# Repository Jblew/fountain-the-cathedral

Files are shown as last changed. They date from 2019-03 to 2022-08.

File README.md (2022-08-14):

# Water Fountain "The Cathedral"

The story behind:

1. AD 1882 — [Antoni Gaudí](https://en.wikipedia.org/wiki/Antoni_Gaud%C3%AD) builds the [Sagrada Família church](https://en.wikipedia.org/wiki/Sagrada_Fam%C3%ADlia)

2. AD 2000 — The Sagrada Familia church inspires [Jacek Dukaj](https://pl.wikipedia.org/wiki/Jacek_Dukaj) to write a short story — ["The Cathedra"](https://pl.wikipedia.org/wiki/Katedra_(opowiadanie)).

3. AD 2002 — [Tomasz Bagiński](https://en.wikipedia.org/wiki/Tomasz_Bagi%C5%84ski) ilustrates the story with his wonderful (and at that time technically astonishing) [animation "The Cathedral"](https://en.wikipedia.org/wiki/The_Cathedral_(film)).

4. AD 2019 — After seeing the Church, watching the Animation and reading the Story (in this order) I decided to build a tribute to the Three Great Artists: Gaudi, Dukaj and Bagiński

They have already used three art techniques: architecture, literature and digital animation. To continue the chain of inspiration I had to choose a different one. 

... continue

## Update

### Stage 1

[See photos](./stage_1/photos.md)

**Done**:

1. Built cathedral backbone of copper wire
2. Secured the backbone with styro foam

### Stage 2

[See photos](./stage_2/photos.md)

**Done:**

1. Selected and prepared 2 granite stones
2. Drilled fi12mm holes for the supporting rods (3 holes in the smaller stone and 7 in the bigger one)
3. Drilled 19 fi8mm holes to attach the cathedral building

**Comment:**

I used diamond hole-saws together with constant water flow (using 450l/h pump). Despite using the maximum rotation speed of the driller it took more than 16 hours to drill all the holes. During the drilling I destroyed 4 saws.

### Stage 3

[See photos](./stage_3/photos.md)

**Done:**

1. I drilled the "magnum foramen" through the centre of the bigger stone. Because of the limited length of the hole-saws I had to mark the position stereotactically and then drill separate holes on each side. Then I used a hammer and steel rods to carefoully chisel the remaining stone from inside.
2. On the upper side I widened the foramen opening using diamond mills (spindle- and ball-shaped). Thanks to that I achived an "anxious" look of the dark and deep hole. What is more — thanks to the wide opening — woter that is flowing upwards through the tunnel doesn't "shoot" in a fountain-like manner. Instead it flows slowly.
3. I drilled many glens, gorgens and faults to guide the direction of water flow. After the procedures water is flowing only in the front direction spreading into an elegant and majestic delta.
4. I drilled supporting tunnels that connect with the main foramen and open on the front waterfall. The idea is to have limited amount of water flowing through the floor of the cathedral while maintaining high flow through the waterfall.

### Stage 4

[See photos](./stage_4/photos.md)

**Done:**

1. First, I encountered a problem of creating a plane model of holes of the bottom side of both stones. When I was drilling them they often were misplaced compared to the original stencil. I had to position the stones correctly and then somehow create another plain stencil. Positioning was demanding since the stones are very heavy. i used wooden blocks and old clothes to precisely position them. To create a stencil I put a huge transparent acrylic glass onto the stones. Using a laser (which I ensured that was staying in a perfectly right angle to the glass) I ensured that the laser dot appears exactly in the middle of each hole. Then I marked the laser spots on the glass. Next step was to drill the holes through the acrylic and copy the appertures of the holes to a semi-transparent engineering paper.
2. Using the stencils I drilled the same set of holes in a wooden 600x600mm shelf which then I hanged above the stones. I inserted fi12mm rods both into the wells in the stones and the holes in the hanging piece of wood. I had to position it using steel wires attached to the ceiling and walls. I used level tool a lot to ensure that all the angles are correctly positioned.
3. I marked the position of the wooden plane on the rods, labelled them with numbers (put the same numbers on the stencil) — and then I cut each rod to end at the exact position of the plane. 
4. After I had each rod lengthened properly  I secured them to the plane with nuts and steel rings which also prevented the plane from oscillating on the steel wires.
5. Then the most time consuming process begun. I had to attach the rods to the stone in an extremly strong and reliable manner. The best idea that appealed to me was to use a "chemical anchor". After studying chemical and physical specs of several of such products I bought a Pattex chemical anchor that was waterproof and was designed exactly for connecting steel and stone. A chemical anchor consists of two ingredients that mix up in a special mixer attached at the end of aplying tool and then are applied directly into the holes.
6. Over the next 4 weekends I was unscrewing 3 rods each time and apply the chemical anchor. Then I needed to leave it for about 18 hours to get a strong bond. Almost half of them didn't mount securely at the first appliance and I had to clean the holes, drill-out the artificial sand and apply it one more time.

### Stage 5

[See photos](./stage_5/photos.md)

**Done:**

1. Built temporary base mad of three old wooden 600x600 shelves
2. Assembled base and the stones on the rods in a vertical position
3. Connected the pump to the bottom tunnel to test the waterflow
4. Using diamond mills I deepened the glens to guide the waterflow in a more even way
5. Sharpened the bottom edge of the fall to prevent water underflowing (and thus corroding the steel rods) 

### Stage 6

[See photos](./stage_6/photos.md)

**Done:**

1. Cleaned the stones with pressure cleaner
2. Removed stone impurities with diamond and corund mills
3. Glued the cathedral backbone using poxillin glue

### Stage 7

[See photos](./stage_7/photos.md)

**Done:**

1. Removed the temorary base
2. Built a new base made of 4x 18mm plywood planes and applied a black glass ontop of that
3. Attached 8 aluminium u-profiles to separate the plywood from the floor.

### Stage 8

(no photos)

1. Designed a way to quickly attach nuts
2. Disassembled old base
3. Covered the entire monument with foil to protect it for the winter (it sits outside)
4. Ordered steel plates to stabilise the rods that support the heavy rocks. I designed an SVG then converted it to CAD file (with some minor adjustments). I ordered laser cutting of 6mm black steel (should get covered with rust very quickly!)
5. Ordered the flowerpot which will be the water reservoir. I have choosen a 300x600x390 one, made of fiberglass with very shiny finish. It's said to be very durable yet it weights only 4kg (compared to concrete ones which (at the same size) weight around 30kg)

### Stage 9

TODO photos

1. Designed and ordered laser-cut steel support plates for water reservoir. Still not assembled

### Stage 10

(no photos)

1. Designing and planning waterfall disperser
2. Main idea: ceramic maple leaves

### Stage 11

Plan:

1. Assemble reservoir circuit
   1. Plan hole positions
   2. Make holes
   3. Apply liquid rubber isolation
   4. Attach electric & water culverts to the reservoir
2. Build reservoir support
   1. Plan height & lengths of rods
   2. Cut feet rods
   3. Make feet holes in the base glass
   4. Make feet holes in the base plywood
   5. Screw on feet rods
3. Build electric 
4. Assemble major parts together
   1. Attach steel stabilisers to the long rods
   2. Attach base to the long rods
   3. Attach reservoir

## Setting

width: 75cm wall + 7cm door border

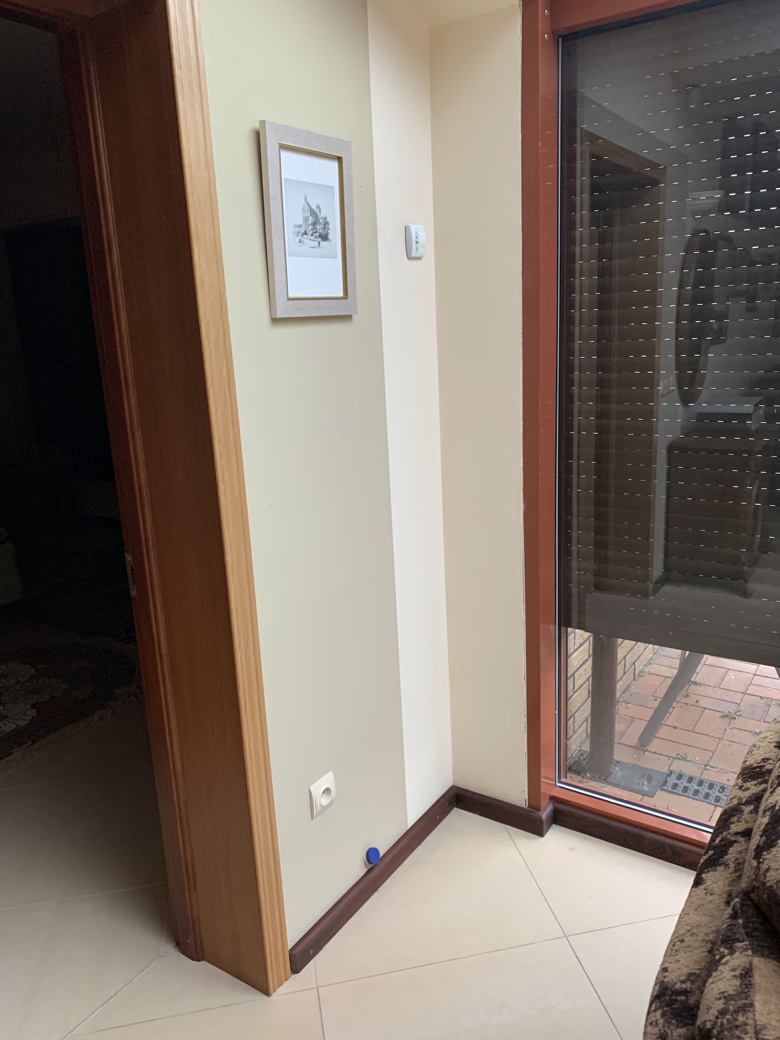
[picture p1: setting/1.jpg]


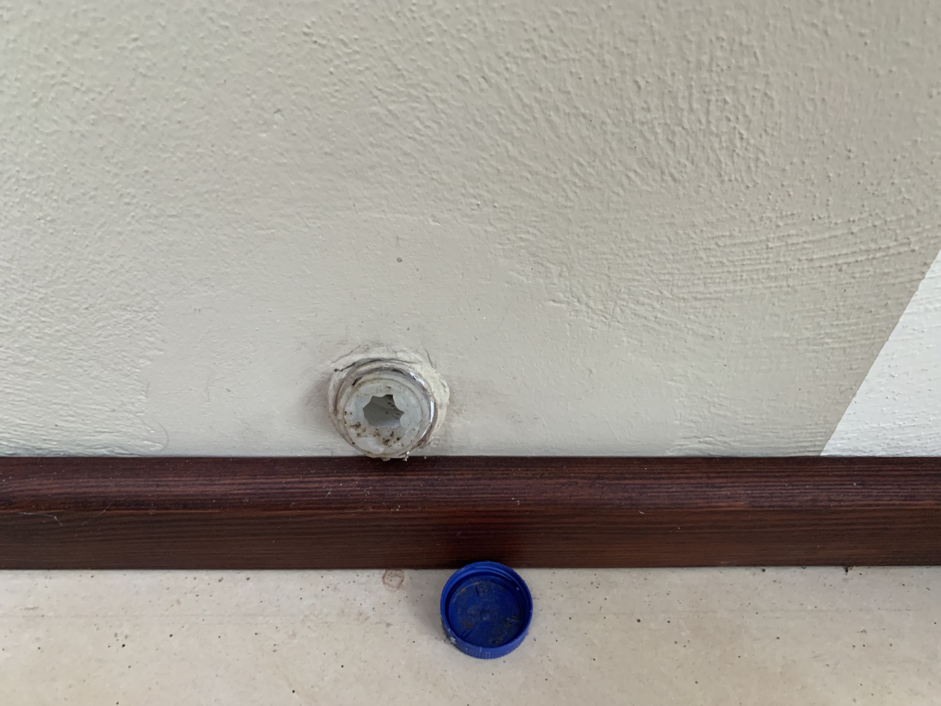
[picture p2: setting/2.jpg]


## Plans

### Steel rods stabilisers

Position of holes (relative to the base — left,deep):

1. 160,302 = 302-160 => 160,142
2. 253,373
3. 298,279
4. 275,157
5. 413,151
6. 494,177
7. 430,279
8. 78,249
9. 102,169
10. 169,157

Todo:

1. Order steel stabilisers

## Water reservoir

Candidates:

1. https://sklep.polnix.com.pl/pl/p/95.010/144
   1. czarna, włókno szklane
   2. 2,9kg, 70l, tj razem z wodą max 70/2+2,9=37,9kg
   3. w=600,d=300,h=390 [mm]
2. https://sklep.polnix.com.pl/pl/p/95.038/133 (jw, ale z nóżkami)

TODO:

1. Design support/fulcrum for the pot (should be anchored in the wooden base and do not burden the glass plane)

## Todo

**Structure:**

1. Stabillise rods that are supporting the stones with:
   1. (either) small welded horizontal rods
   2. (either) use multiple convolutions of thick nickel plated wire attached with nuts and glue shaped into ivory-like structure
   3. (either) use thick barbed wire attached with nuts and glue
2. Apply rusting mixture to rust the rods. (If using nickel wires to stabilise the supporting rods: scratch the nickel wires with coarse-grained emery paper). Then secure the rust with water resistant transparent (and nonglowing!) coat.

## Water circuit

Reservoir

Pump circuit:

1. - [x] Nypel 1/2" -> 3/4" m/m
2. - [x] Wąż 3/4" f/f 100cm (internal fi 19mm)
3. - [x] Nypel 3/4" m/m
4. - [x] Redukcja nypel 3/4" -> mufa 1"
5. - [x] Przepust m1" -> f3/4"
6. - [x] Nypel 3/4" m/m
7. - [x] Wąż 3/4" f/f 30cm (internal fi 19mm)
8. - [x] Nypel m3/4" -> f1/2"
9. - [x] Nypel 1/2" -> plastik 13mm (dołączony do pompy)

Reservoir refill circuit

1. - [x] 2x Przepust f1/2" -> m3/4"
2. - [x] 2x Wąż 3/4" f/f 50cm (internal fi 19mm)
3. - [x] 2x Nypel m3/4" -> f1/2"
4. - [x] 2x elektrozawór 1/2" m/m
5. - [x] 2x zawór kulowy 1/2" f/m
6. - [x] 2x wąż 1/2" 150cm m/m

**Cathedral:**

1. Coat the cathedral with copper wire of decreasing sizes
2. Design and build the Altar
3. Design 3D model of the Priest and order it
4. Design 3D model of Saint Ismir's grave
5. Form and attach a Cross on the top
6. Distort the shape of the fully assembled cathedral so that it looks haunted and almost falling
7. Apply blue-copper-corrosion mixture and secure with transparent (glowing!) coating

**Water system:**

1. Choose and buy flowerpot for a tank
2. Design and assembly water automation
3. shape the waterfall edge to ensure that water is flowing into the tank without spilling

**Plants:**

1. Buy and attach Hedera helix ivory (darkest possible shade of the leaves)
2. Design and assembly ivory watering system

**Target site assembly:**

1. Mount black glass to the wall behind the fountain to prevent destroying wall plaster, also if the background is black and glowing:  the base, rods, ivory, the stones will be less striking while emphasizing the blue-and-ginger glowing cathedral.

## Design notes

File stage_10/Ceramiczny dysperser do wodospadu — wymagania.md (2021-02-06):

# Ceramiczny dysperser do wodospadu — wymagania

1. Ceramika: czarna, szkliwiona na połysk
2. Liście w trzech rozmiarach, odpowiednio do naturalnych liści klonu. 14x duży liść, 14x średni liść, 14x mały liść
3. 2 otwory w każdym liściu, przy podstawie — średnica od 5mm do 8mm, odległość od 10 do 15mm pomiędzy nimi
4. Każdy liść lekko zagięty na brzegach i do wewnątrz (skulony), tak, żeby niewielka ilość wody mogła się tam zebrać (one będą zamontowane pod kątem 45 stopni do pionu)

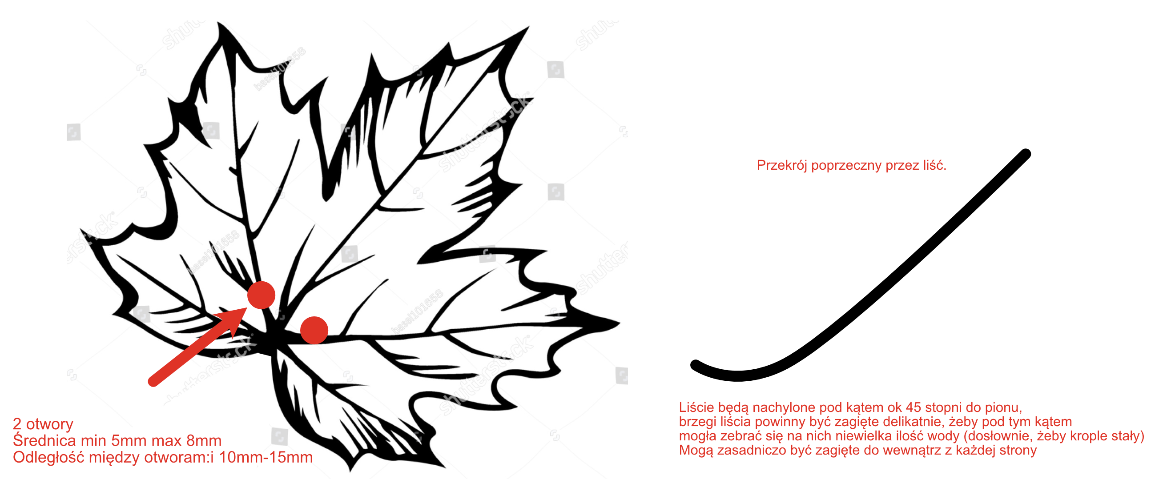
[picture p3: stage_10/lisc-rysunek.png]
lisc-rysunek


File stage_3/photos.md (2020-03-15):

# Stage 3 photos

[Back to the README](../README.md)











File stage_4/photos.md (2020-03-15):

# Stage 4 photos

[Back to the README](../README.md)

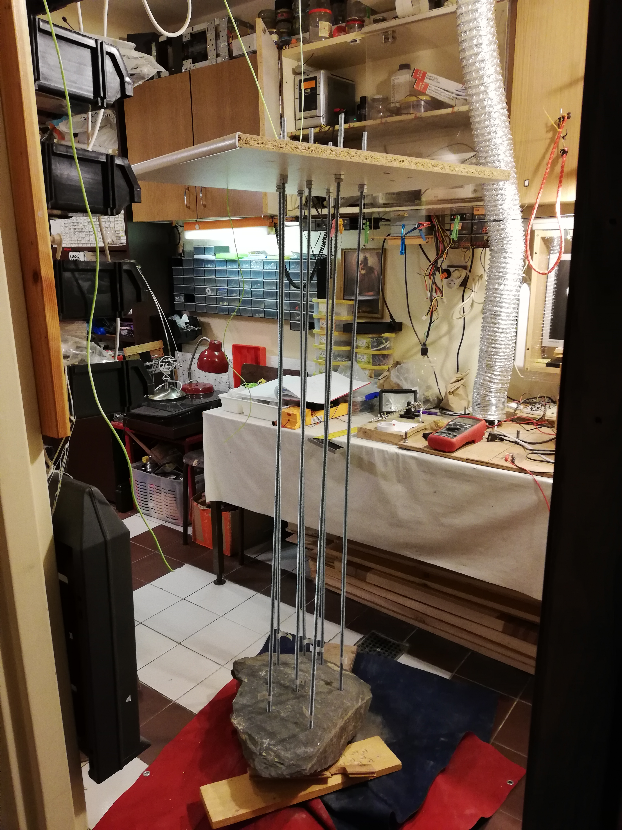
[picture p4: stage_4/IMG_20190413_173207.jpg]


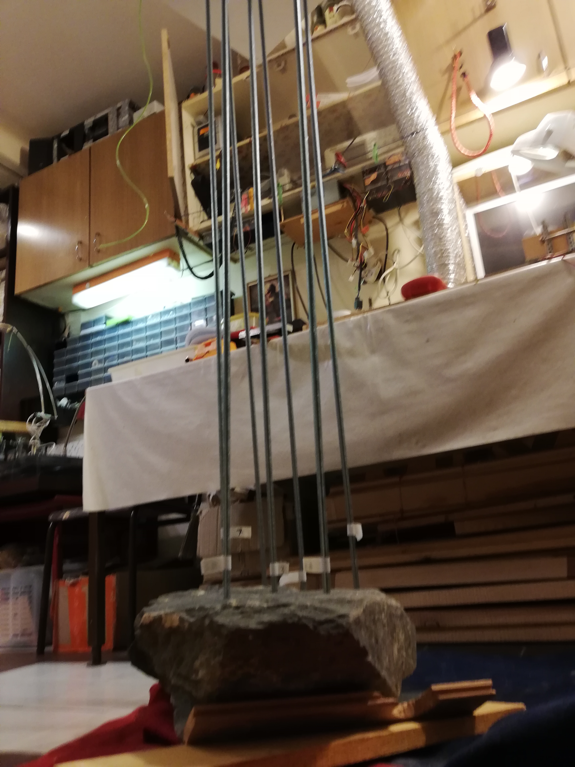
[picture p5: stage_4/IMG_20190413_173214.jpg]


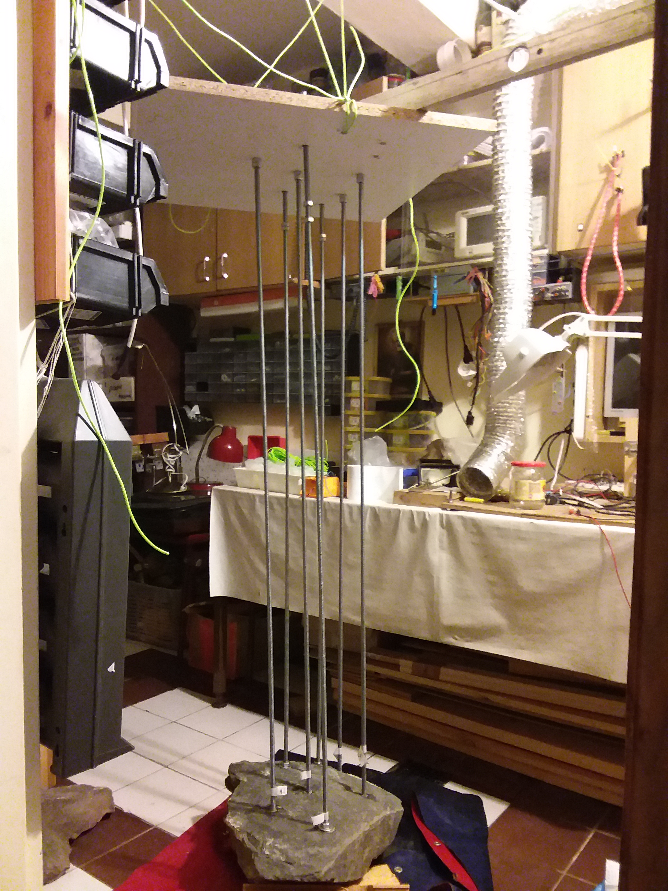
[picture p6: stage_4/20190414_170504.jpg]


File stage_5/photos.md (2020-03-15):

# Stage 5 photos

[Back to the README](../README.md)

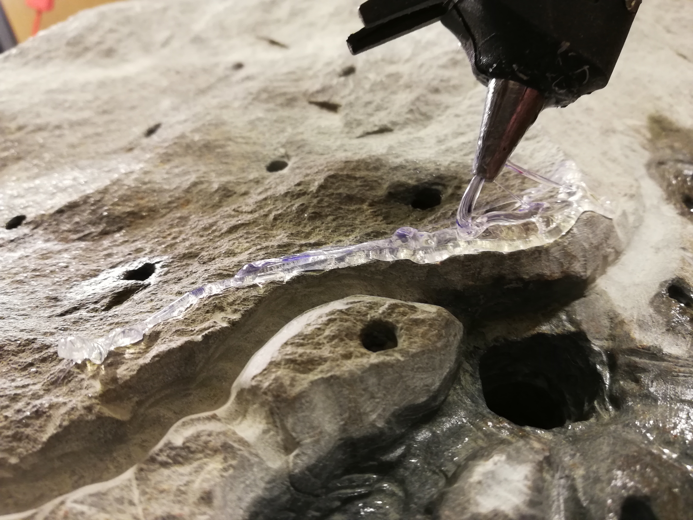
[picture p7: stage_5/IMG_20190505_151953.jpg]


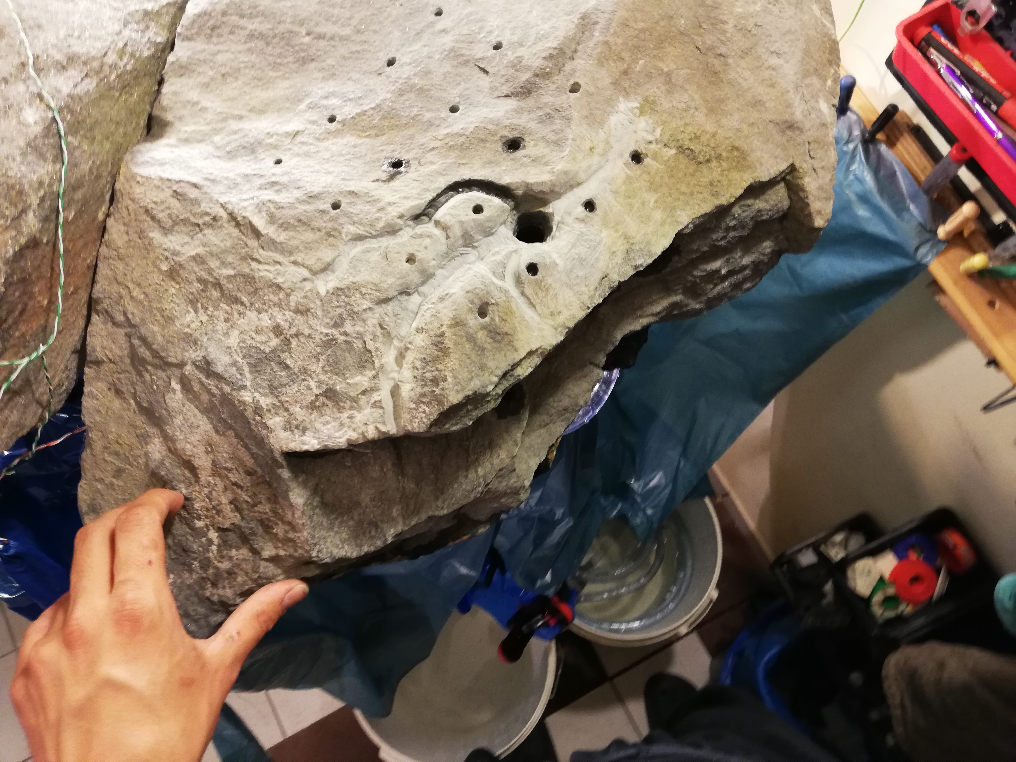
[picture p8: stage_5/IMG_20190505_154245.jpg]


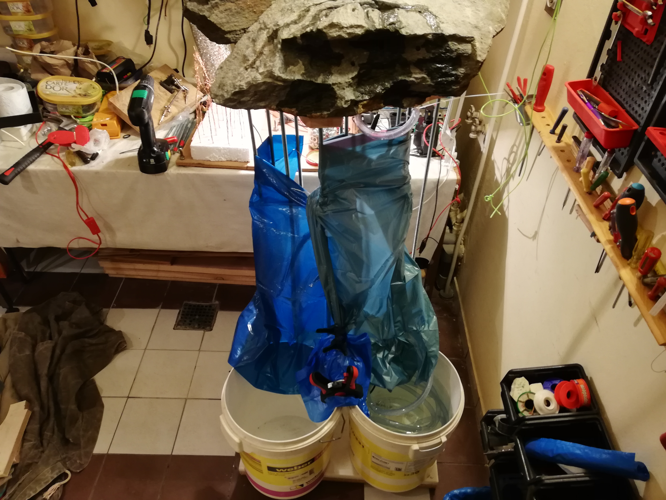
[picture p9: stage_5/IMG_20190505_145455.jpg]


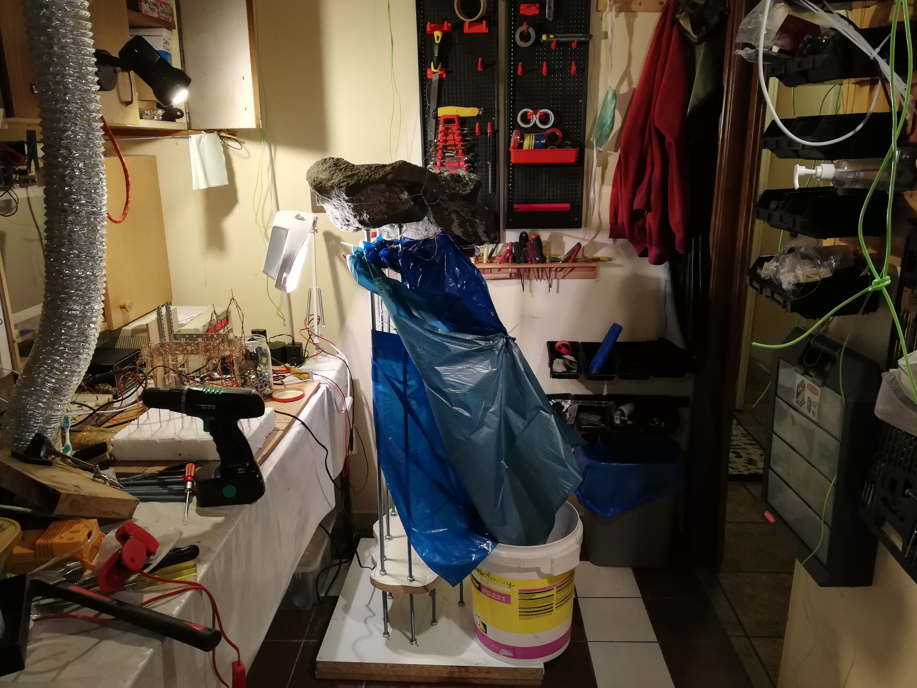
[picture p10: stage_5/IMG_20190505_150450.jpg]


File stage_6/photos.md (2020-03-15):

# Stage 6 photos

[Back to the README](../README.md)











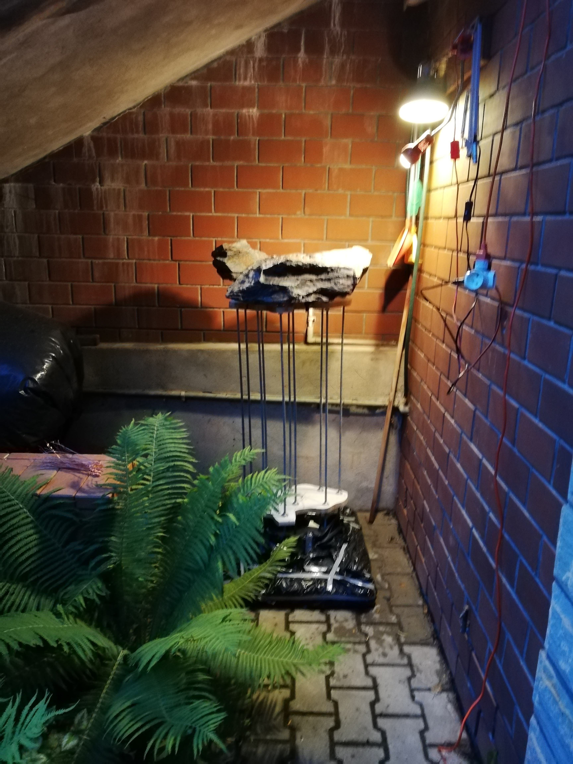
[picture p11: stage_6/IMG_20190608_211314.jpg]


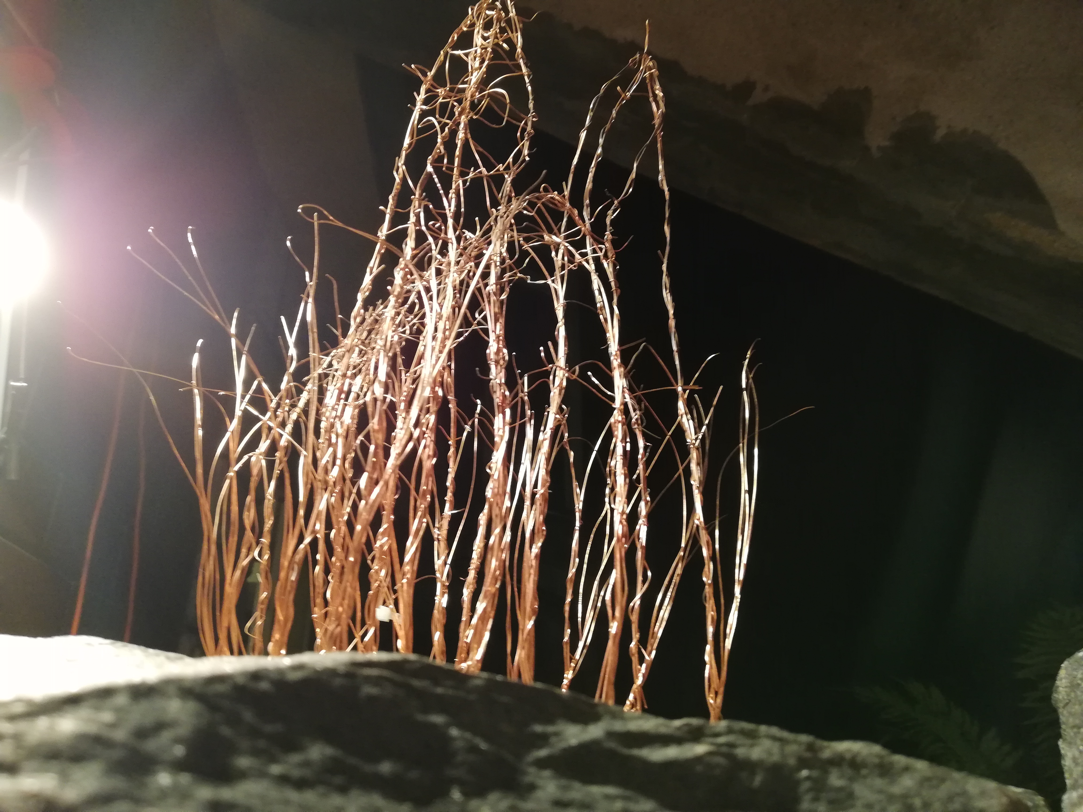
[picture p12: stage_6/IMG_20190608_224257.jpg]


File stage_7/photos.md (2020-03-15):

# Stage 7 photos

[Back to the README](../README.md)

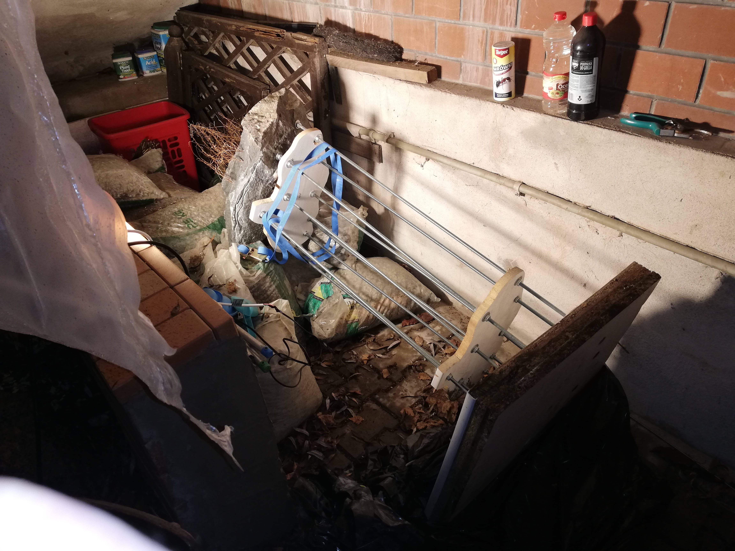
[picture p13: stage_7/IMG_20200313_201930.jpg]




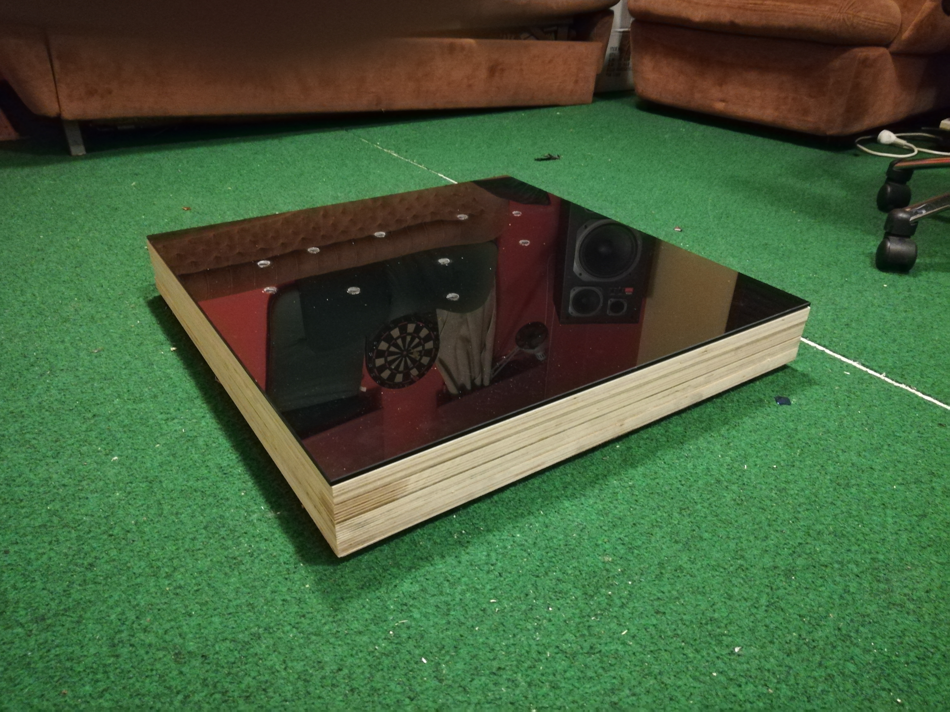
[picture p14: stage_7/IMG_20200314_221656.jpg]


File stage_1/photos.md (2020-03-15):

# Stage 1 photos

[Back to the README](../README.md)

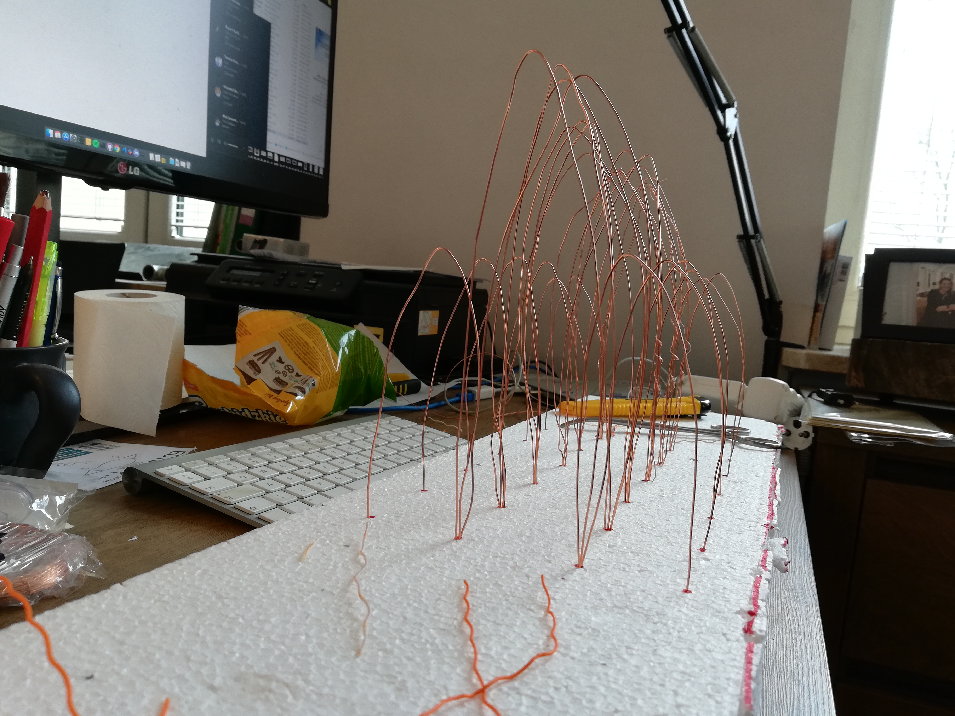
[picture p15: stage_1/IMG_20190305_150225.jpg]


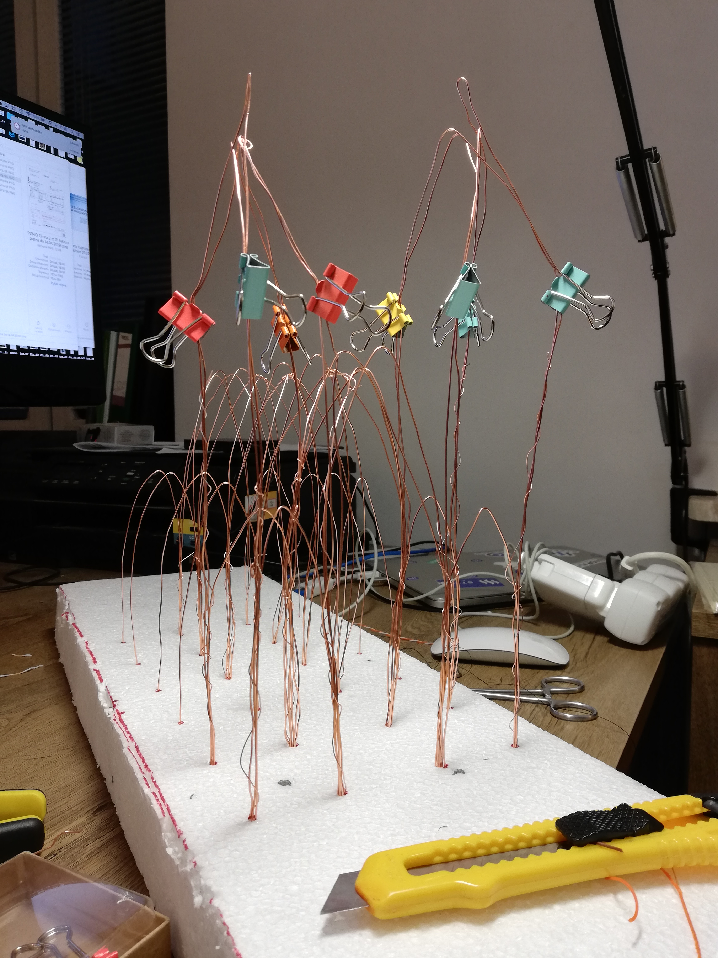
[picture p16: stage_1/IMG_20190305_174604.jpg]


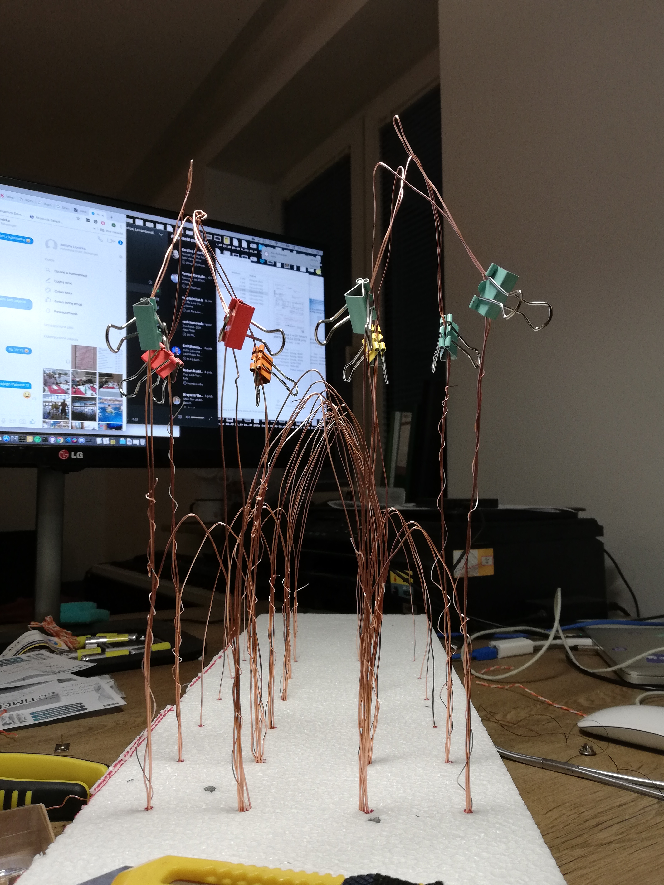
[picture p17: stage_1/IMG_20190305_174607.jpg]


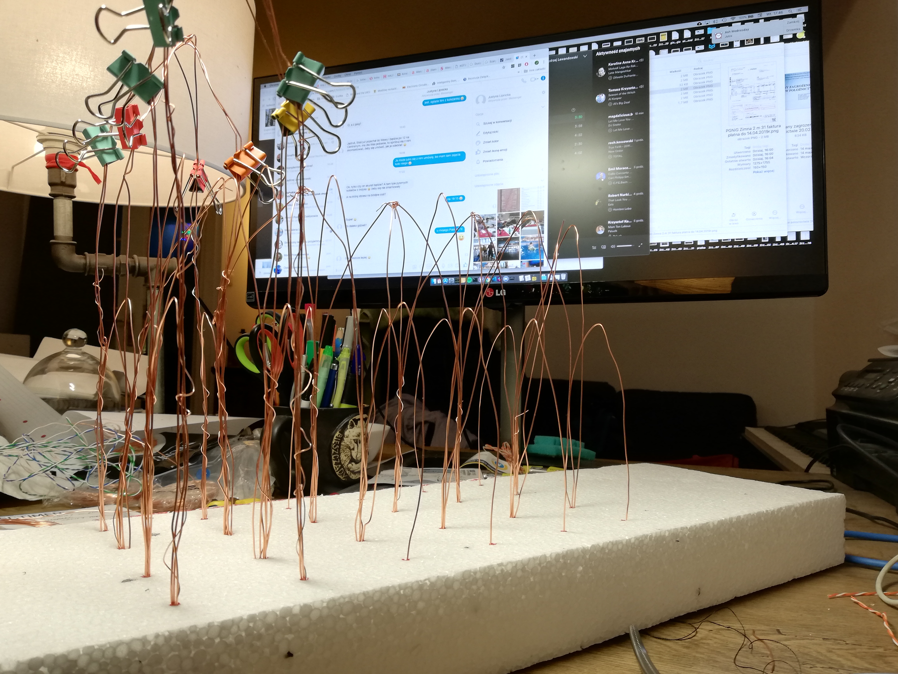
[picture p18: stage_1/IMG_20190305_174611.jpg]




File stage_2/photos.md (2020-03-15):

# Stage 2 photos

[Back to the README](../README.md)













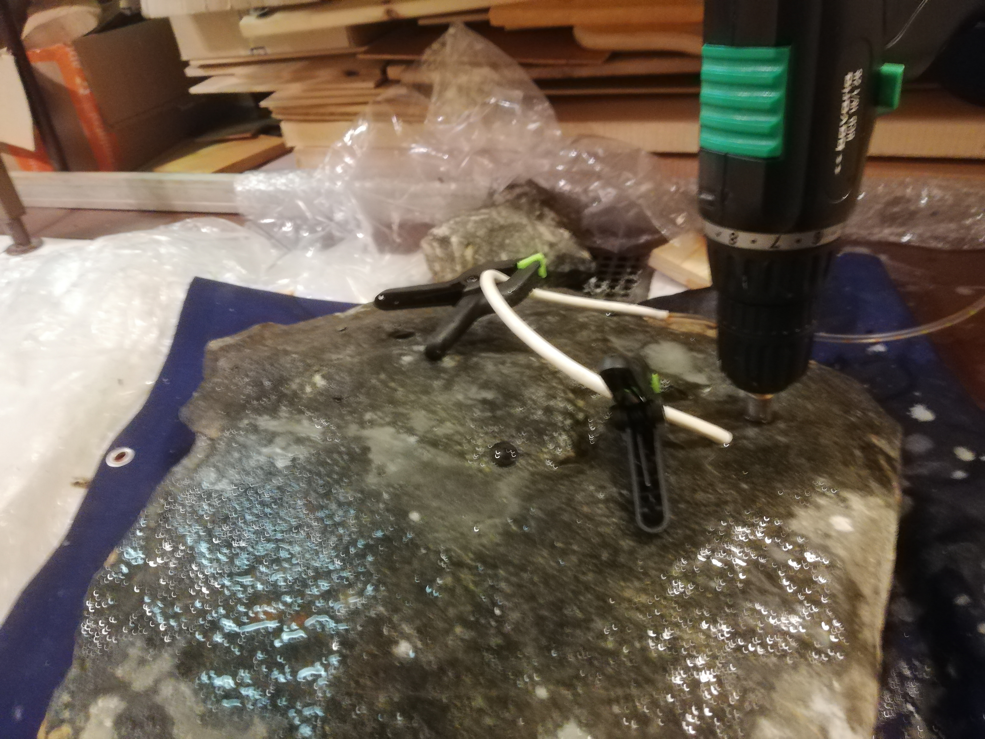
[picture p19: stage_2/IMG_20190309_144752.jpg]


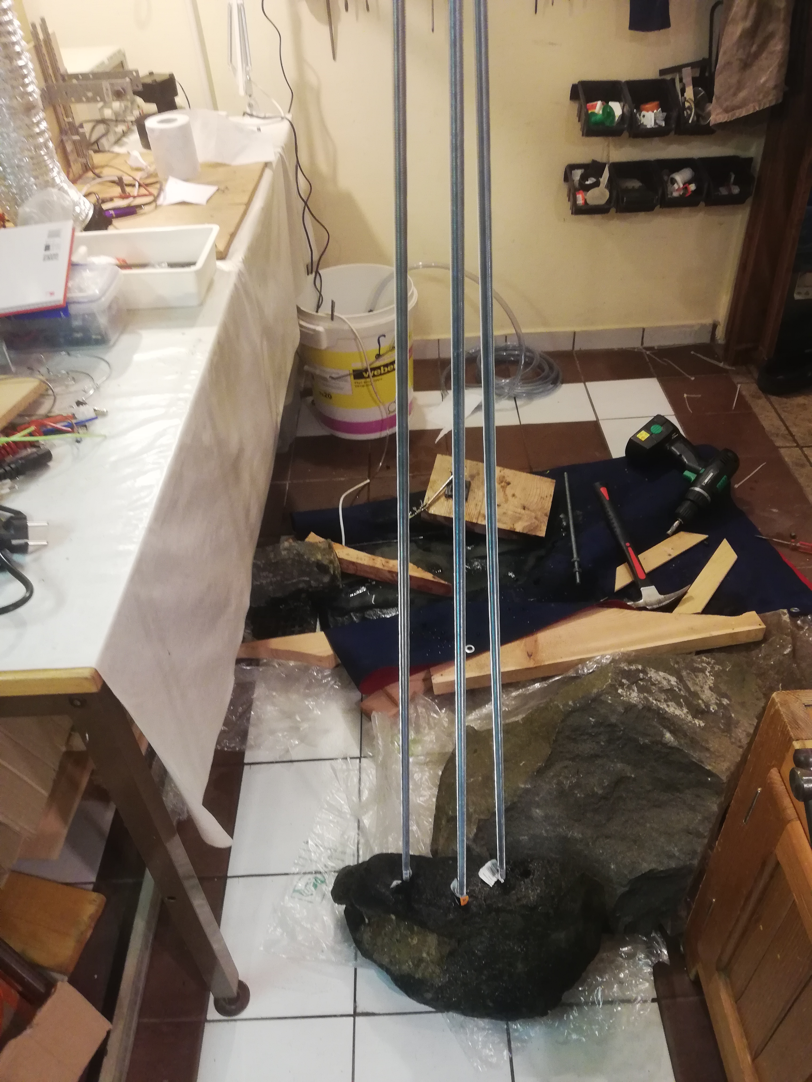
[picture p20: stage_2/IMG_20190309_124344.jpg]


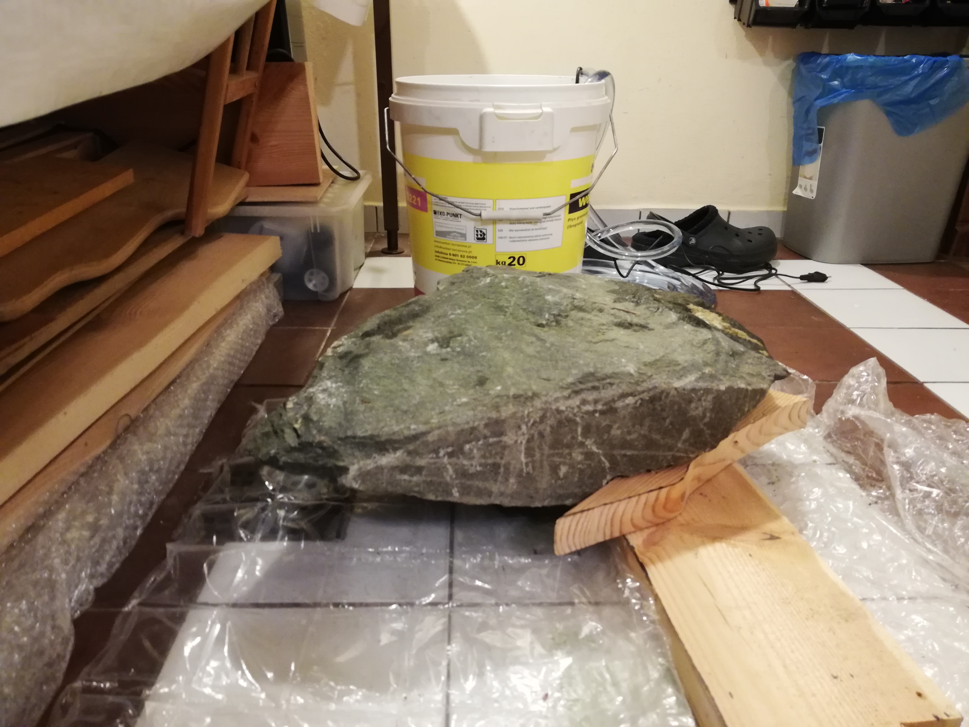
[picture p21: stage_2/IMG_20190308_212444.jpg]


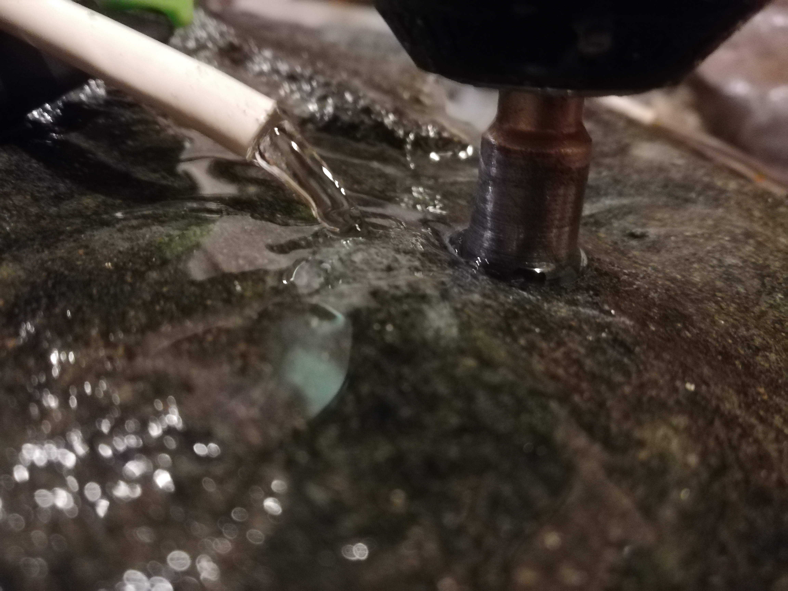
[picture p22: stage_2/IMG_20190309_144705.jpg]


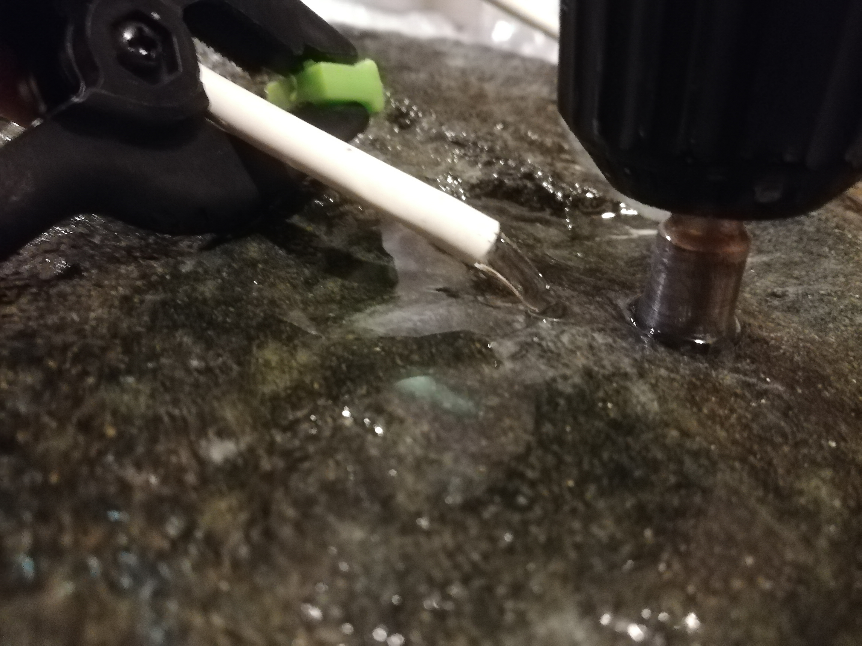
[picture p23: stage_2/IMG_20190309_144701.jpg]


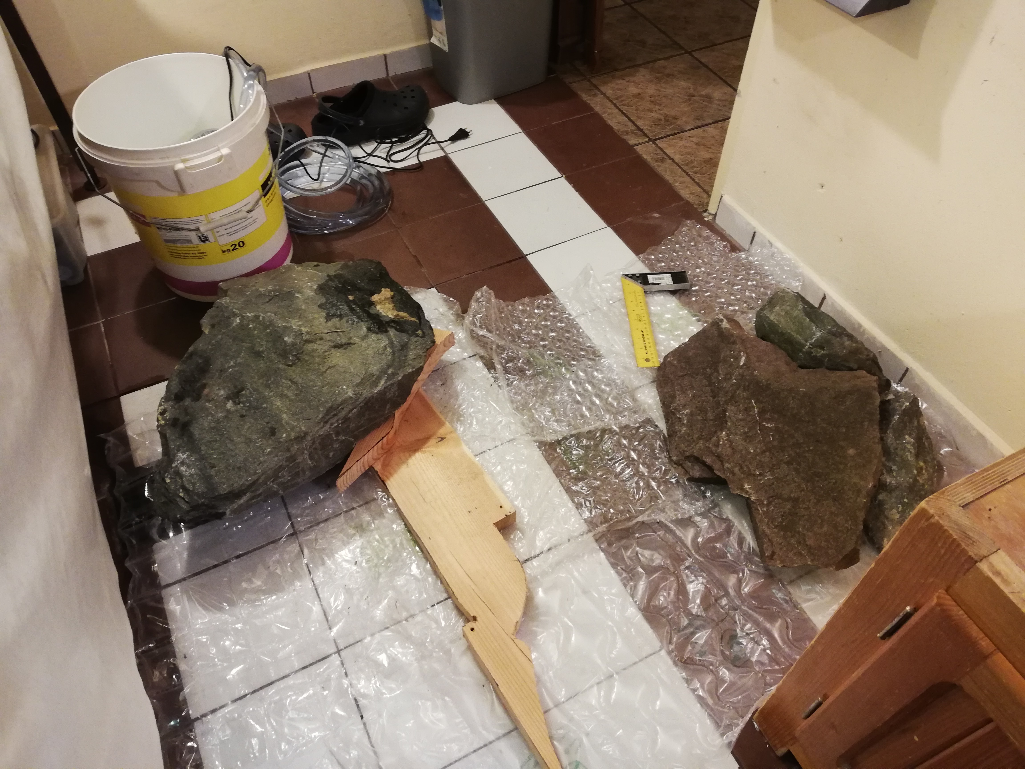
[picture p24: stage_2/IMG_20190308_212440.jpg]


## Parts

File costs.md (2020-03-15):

# Costs

1. Steel rods 10x2000 8pcs + screw caps — 65zł
2.

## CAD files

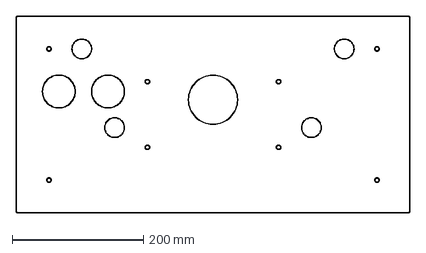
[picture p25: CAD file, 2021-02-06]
steel-support-cad/reservoir-support.dxf
600.0 x 300.0 mm

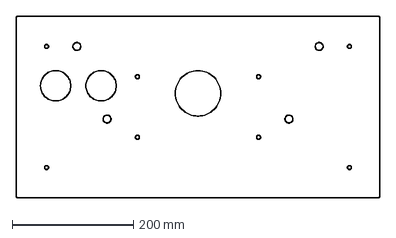
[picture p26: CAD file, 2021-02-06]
steel-support-cad/reservoir-support-l2.dxf
600.0 x 300.0 mm

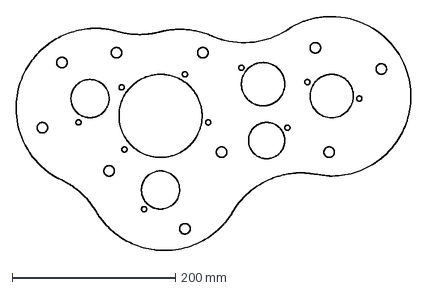
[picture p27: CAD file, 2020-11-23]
steel-support-cad/stblt_plate_stal_czarna_484x287_6mm.dxf
484.5 x 287.0 mm

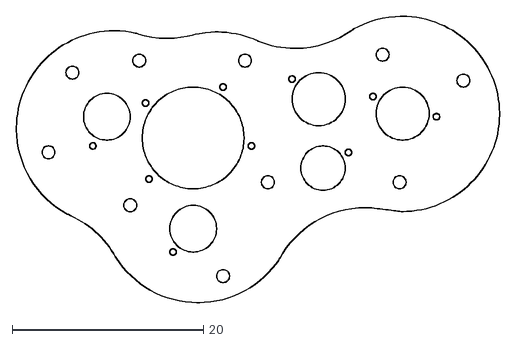
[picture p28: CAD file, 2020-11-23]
steel-support-cad/steel-support-cropped-svg.dxf
50.5 x 29.9

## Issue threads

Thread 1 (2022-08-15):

EPIC Assemble the monument

Jblew, 2022-08-15:
- [ ] Install first stabilizing plate
- [ ] Clean and re-apply failed chemical anchors
- [ ] Install remaining stabilizing plates
- [ ] Adapt base for wheels & electric box & reservoir support
- [ ] Assemble water reservoir with support
- [ ] Install base
- [ ] Install water reservoir
- [ ] Rotate and transport the monument

Jblew, 2022-10-02:
Descheduled

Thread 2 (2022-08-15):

Install first stabilizing plate

Jblew, 2022-08-15:
- [x] Find idea for quick screw/unscrew on long M10 rods
- [x] Stabilizing plates
- [x] Two French keys for M10 nuts
- [x] Chemical anchor with clean application tube
- [x] M10 bolts
- [x] M10/stabilizer hole bolt washers

Jblew, 2022-08-17:
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

Closed 2022-08-17.

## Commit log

2019-03-17 Add stage 1,2,3 photos
2020-03-15 feat: stage 4 photos
2020-03-15 feat: stage 5 photos
2020-03-15 feat: stage 6 images
2020-03-15 feat: stage 7 images
2020-03-15 feat: Stage 1 photos page
2020-03-15 feat: Stage 1 and stage 2 description
2020-03-15 feat: Stage 3 description
2020-03-15 feat: Stage 4 description
2020-03-15 feat: Stage 5, 6, 7 description
2020-11-23 feat: cad drawings of steel support plate
    [stblt_plate_stal_czarna_484x287_6mm.dxf, steel-support-cropped-svg.dxf]
2021-02-06 feat: reservoid cad design
    [reservoir-support-l2.dxf, reservoir-support.dxf]
